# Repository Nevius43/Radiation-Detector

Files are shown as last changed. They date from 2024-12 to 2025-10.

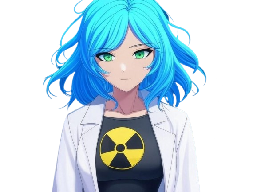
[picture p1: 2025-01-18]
User Interface/SquareLineFiles/cache/thumb_83886609image-removebg-preview.png

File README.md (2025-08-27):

# ESP32-S3 Radiation Detector

A small, open-source handheld **radiation detector/logger** based on the **ESP32-S3**.  
It reads a **Geiger–Müller (GM) tube** and can optionally handle a **scintillation probe (CsI(Tl) + SiPM)**.  
Data is shown on a **4" SPI TFT** and can be logged to **microSD**.

> ⚠️ **Safety:** This project uses **high voltage (≈400–600 V)** and is **not** a certified dosimeter. Build and use at your own risk.

---

## Features
- Live CPS/CPM and rough µSv/h estimate (tube-dependent factor).
- Optional scintillation input through a simple analog chain + discriminator.
- 4" SPI TFT with resistive touch; buzzer clicks/alarms.
- microSD CSV logging (timestamp, cps/cpm, battery, HV, etc.).
- Li-Po power, USB charging, 3.3 V buck; battery voltage monitor.
- Simple config via `src/config.h`. PlatformIO project.

---

## Hardware (summary)
- **MCU:** ESP32-S3-WROOM-1U-N16R8  
- **Display:** ST7796S (SPI) + XPT2046 touch (SPI)  
- **Storage:** microSD (SPI)  
- **GM subsystem:** HV boost (~500 V) + GM input (e.g., Philips 18504)  
- **Optional scintillation:** CsI(Tl) + SiPM (e.g., MicroFC-60035)  
- **Power:** MCP73831 charger, SY8089 buck, battery divider to ADC

Full schematics/PCB are in `/PCB`.

---

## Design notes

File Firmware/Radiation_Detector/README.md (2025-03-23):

# Radiation Detector

A digital radiation monitoring system built on the ESP32-S3 platform with real-time radiation measurement, visualization, data logging, and wireless connectivity.

Radiation Detector

## Overview

This radiation detector project combines an ESP32-S3 microcontroller with a Geiger counter to create a versatile digital radiation monitoring system. It features a touchscreen TFT display for data visualization, WiFi connectivity for remote monitoring, and OTA (Over-The-Air) update capabilities.

The system provides:

- Real-time measurement of radiation levels in µSv/h
- Historical data visualization with 1-hour and 24-hour charts
- Customizable alarm thresholds for radiation levels
- Web dashboard for remote monitoring
- OTA firmware updates
- mDNS support for easy access via "radiation.local"

## Hardware Requirements

- ESP32-S3 development board
- Geiger counter module (connected to GPIO 9)
- 3.5" TFT display (480x320)
- Buzzer (connected to GPIO 38)
- USB power supply

## Software Architecture

The project is built with PlatformIO and Arduino framework and consists of several key components:

1. **Radiation Measurement** - Uses ESP32's PCNT (Pulse Counter) peripheral to count pulses from the Geiger counter
2. **User Interface** - LVGL-based touchscreen interface with multiple screens
3. **Data Visualization** - Real-time and historical charts showing radiation levels
4. **Web Dashboard** - Remote monitoring capabilities
5. **OTA Updates** - Wireless firmware update functionality
6. **mDNS Support** - Local network hostname resolution (radiation.local)

## Installation

### Prerequisites

- [PlatformIO](https://platformio.org/) (with VS Code or CLI)
- The following libraries (installed automatically via PlatformIO):
  - LVGL (for UI)
  - TFT_eSPI (for display)
  - ArduinoJson
  - ElegantOTA
  - ESPmDNS

### Building and Flashing

1. Clone the repository:
   ```
   git clone https://github.com/username/Radiation-Detector.git
   ```

2. Open the project in PlatformIO:
   ```
   cd Radiation-Detector
   platformio open
   ```

3. Build and upload to your ESP32-S3:
   ```
   platformio run --target upload
   ```

## Usage

### Physical Interface

The device starts with a startup screen showing the bootup sequence. Once initialized:

1. **Main Screen** - Displays current radiation readings with four key metrics:
   - Current Radiation (µSv/h)
   - Average Radiation (µSv/h)
   - Maximum Radiation (µSv/h)
   - Cumulative Dose (mSv)

2. **Charts Screen** - Provides visual history of radiation levels:
   - 1-hour chart (20 segments of 3-minute averages)
   - 24-hour chart (24 segments of 1-hour averages)

3. **Settings Screen** - Configuration options:
   - WiFi connection setup
   - Alarm threshold settings
   - Display settings

### Web Interface

Once connected to WiFi, the device hosts a web dashboard accessible through:

- IP address (displayed on the screen)
- mDNS hostname: http://radiation.local

The web dashboard provides:
- Current radiation readings
- Historical charts
- OTA update functionality (with safety confirmation)

## Configuration

### WiFi Setup

1. On the Settings screen, enter your WiFi credentials
2. Toggle "Connect on Startup" to enable automatic connection
3. Press "Connect" to initiate connection

### Alarm Settings

1. Navigate to the Settings screen
2. Set threshold for current radiation level (µSv/h)
3. Set threshold for cumulative dose (mSv)
4. Enable/disable alarm function using the checkbox

## Technical Details

### Radiation Measurement

- The system uses an ESP32 PCNT peripheral to count pulses from the Geiger counter
- Pulses are sampled every 100ms and accumulated into 1-second intervals
- Conversion factor: 153.8 pulses/minute = 1 µSv/h (calibrated for specific Geiger tube)
- 60-second running average for current readings to reduce statistical noise

### Data Visualization

- 1-hour chart: 20 segments, each representing a 3-minute average
- 24-hour chart: 24 segments, each representing a 1-hour average
- Dynamic Y-axis scaling based on measured values

### Power Management

- Display dimming after 5 minutes of inactivity
- Touch anywhere to restore display brightness
- USB-powered design (no battery monitoring)

## OTA Updates

The device supports Over-The-Air updates via the web interface:

1. Access the web dashboard at http://radiation.local
2. Navigate to the update page
3. Review and acknowledge the warning
4. Select and upload the new firmware file

## Development

### Project Structure

- `src/Radiation-Detector.cpp` - Main application code
- `src/dashboard.*` - Web dashboard implementation
- `src/radiation_data.h` - Data exchange interface
- `src/ui.*` - UI components and layout

### Adding Features

To extend the project:

1. Modify UI elements in `ui.c` and `ui.h`
2. Update web dashboard in `dashboard.cpp`
3. Add new hardware interfaces in `Radiation-Detector.cpp`

## Troubleshooting

- **WiFi Connection Issues**: Check credentials, try manual connection
- **No Radiation Readings**: Verify Geiger counter connection to GPIO 9
- **Display Not Working**: Check TFT connections and initialization
- **OTA Update Failing**: Ensure stable WiFi connection, verify firmware file

## License

This project is licensed under the MIT License - see the LICENSE file for details.

## Acknowledgments

- LVGL for the UI framework
- TFT_eSPI library for display support
- ElegantOTA for update functionality
- ESPmDNS for local hostname support

## Safety Warning

This device is meant for educational and hobbyist purposes only. It should not be used as a primary radiation safety device in hazardous environments. Always use certified radiation detection equipment for critical safety applications.

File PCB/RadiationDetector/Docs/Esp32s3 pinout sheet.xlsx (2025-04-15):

1 | GND_1
2 | 3V3
3 | EN
4 | GPIO4/RTC_GPIO4/TOUCH4/ADC1_CH3
5 | GPIO5/RTC_GPIO5/TOUCH5/ADC1_CH4
6 | GPIO6/RTC_GPIO6/TOUCH6/ADC1_CH5
7 | GPIO7/RTC_GPIO7/TOUCH7/ADC1_CH6
8 | GPIO15/RTC_GPIO15/U0RTS/ADC2_CH4/XTAL_32K_P
9 | GPIO16/RTC_GPIO16/U0CTS/ADC2_CH5/XTAL_32K_N
10 | GPIO17/RTC_GPIO17/U1TXD/ADC2_CH6
11 | GPIO18/RTC_GPIO18/U1RXD/ADC2_CH7/CLK_OUT3
12 | GPIO8/RTC_GPIO8/TOUCH8/ADC1_CH7/SUBSPICS1
13 | USB_D/RTC_GPIO19/GPIO19/U1RTS/ADC2_CH8/CLK_OUT2
14 | USB_D+/RTC_GPIO20/GPIO20/U1CTS/ADC2_CH9/CLK_OUT1
15 | GPIO3/RTC_GPIO3/TOUCH3/ADC1_CH2
16 | GPIO46
17 | GPIO9/RTC_GPIO9/TOUCH9/ADC1_CH8/FSPIHD/SUBSPIHD
18 | GPIO10/RTC_GPIO10/TOUCH10/ADC1_CH9/FSPICS0/FSPIIO4/SUBSPICS0
19 | GPIO11/RTC_GPIO11/TOUCH11/ADC2_CH0/FSPID/FSPIIO5/SUBSPID
20 | GPIO12/RTC_GPIO12/TOUCH12/ADC2_CH1/FSPICLK/FSPIIO6/SUBSPICLK
21 | GPIO13/RTC_GPIO13/TOUCH13/ADC2_CH2/FSPIQ/FSPIIO7/SUBSPIQ
22 | GPIO14/RTC_GPIO14/TOUCH14/ADC2_CH3/FSPIWP/FSPIDQS/SUBSPIWP
23 | GPIO21/RTC_GPIO21
24 | GPIO47/SPICLK_P_DIFF/SUBSPICLK_P_DIFF
25 | GPIO48/SPICLK_N_DIFF/SUBSPICLK_N_DIFF
26 | GPIO45
27 | GPIO0/RTC_GPIO0
28 | GPIO35/SPIIO6/FSPID/SUBSPID
29 | GPIO36/SPIIO7/FSPICLK/SUBSPICLK
30 | GPIO37/SPIDQS/FSPIQ/SUBSPIQ
31 | GPIO38/FSPIWP/SUBSPIWP
32 | MTCK/GPIO39/CLK_OUT3/SUBSPICS1
33 | MTDO/GPIO40/CLK_OUT2
34 | MTDI/GPIO41/CLK_OUT1
35 | MTMS/GPIO42
36 | U0RXD/GPIO44/CLK_OUT2
37 | U0TXD/GPIO43/CLK_OUT1
38 | GPIO2/RTC_GPIO2/TOUCH2/ADC1_CH1
39 | GPIO1/RTC_GPIO1/TOUCH1/ADC1_CH0
40 | GND_2
41 | GND_3
42 | GND_4
43 | GND_5
44 | GND_6
45 | GND_7
46 | GND_8
47 | GND_9
48 | GND_10
49 | GND_11

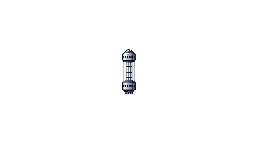
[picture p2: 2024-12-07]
User Interface/SquareLineFiles/cache/thumb_86797815Diseño sin título.png

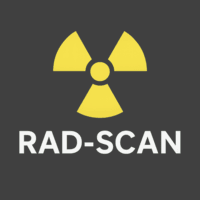
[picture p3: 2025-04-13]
User Interface/SquareLineFiles/assets/RadScan200x200.png

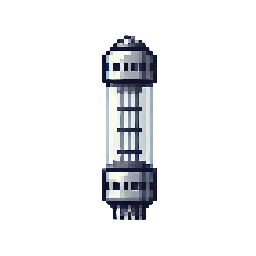
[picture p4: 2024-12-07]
User Interface/SquareLineFiles/cache/thumb_1336107941GMtube.png

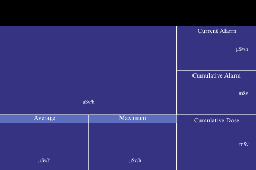
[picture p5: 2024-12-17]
User Interface/SquareLineFiles/cache/thumb_735237340El texto del párrafo.png

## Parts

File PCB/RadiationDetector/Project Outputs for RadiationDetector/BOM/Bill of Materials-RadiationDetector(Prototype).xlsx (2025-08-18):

Comment | Description | Designator | Footprint | LibRef | Quantity | LCSC Part Number | Manufacturer Part Number | Supplier Part Number | Supplier | Manufacturer
1uF, 16V | CAP CER 1UF 16V X5R 0402 | C3, C25 | CAP 0402_1005 | CL05A105KO5NNNC | 2 | C29266 | CL05A105KO5NNNC | 1276-1067-1-ND | Digikey | Samsung Electro-Mechanics
10uF, 10V | CAP CER 10UF 10V X5R 0402 | C4, C15 | CAP 0402_1005 | CL05A106MP8NUB8 | 2 | C307415 | CL05A106MP8NUB8 | 1276-6830-1-ND | Digikey | Samsung Electro-Mechanics
0.1uF, 50V | CAP CER 0.1UF 50V X7R 0402 | C5, C6, C8, C9, C10, C11, C14, C16, C22, C24 | CAP 0402_1005 | CL05B104KB5NNNC | 10 | C960916 | CL05B104KB5NNNC | CL05B104KB5NNNC | Avnet | Samsung
4u7 6.3V | CAP CER 4.7UF 6.3V X5R 0402 | C7, C17, C18 | CAP 0402_1005 | CL05A475KQ5NRNC | 3 | C2932473 | CL05A475KQ5NRNC | 1276-1481-1-ND | Digikey | Samsung
470p 50V | CAP CER 470PF 50V X7R 0402 | C12 | CAP 0402_1005 | CL05B471KB5VPNC | 1 | C472438 | CL05B471KB5VPNC | 1276-6586-1-ND | Digikey | Samsung
220p 50V | CAP CER 220PF 50V X7R 0402 | C13, C29 | CAP 0402_1005 | CL05B221KB5NNNC | 2 | C296710 | CL05B221KB5NNNC | 1276-1531-1-ND | Digikey | Samsung
2 Pin JST | Board Connector, 2 Contact(s), 1 Row(s), Male, Straight, 0.079 inch Pitch, Solder Terminal, Locking, Natural Insulator | C19 | JST_B2B-PH-K-S | B2B-PH-K-S(LF)(SN) | 1 | C131337 | B2B-PH-K-S(LF)(SN) | 9491856 | Farnell | JST
22u 6.3V | CAP CER 22UF 6.3V X5R 0603 | C20, C21 | CAPC1608X90 | CL10A226MQ8NRNC | 2 | C59461 | CL10A226MQ8NRNC | 1276-1193-1-ND | Digikey | Samsung
220u 6.3V | CAP CER 220UF 6.3V X5R 1210 | C23 | ANTC3225X280N | CL32A227MQVNNNE | 1 | C400951 | CL32A227MQVNNNE | 1276-3375-6-ND | Digikey | Samsung
10nF 1KV | CAP CER 10000PF 1KV X7R 1206 | C26, C27 | CAP 1206_3216 - 1.2MM | CC1206KKX7RCBB103 | 2 | C107192 | CC1206KKX7RCBB103 | 311-1500-1-ND | Digikey | Yageo
330pF 100V | CAP CER 330PF 100V C0G/NPO 0805 | C28 | CAPC2012X94N | CC0805JRNPO0BN331 | 1 | C113820 | CC0805JRNPO0BN331 | 311-3287-1-ND | Digikey | Yageo
10 pF 1KV | CAP CER 10PF 1KV C0G/NPO 1206 | C31 | CAP 1206_3216 - 1.2MM | CC1206JKNPOCBN100 | 1 | C107172 | CC1206JKNPOCBN100 | 311-1912-6-ND | Digikey | Yageo
1N5819HW-7-F | DIODE SCHOTTKY 40V 1A SOD123 | D1, D5, D11 | FP-SOD123-MFG | 1N5819HW-7-F | 3 | C82544 | 1N5819HW-7-F | 1N5819HW-FDICT-ND | Digikey | Diodes
ESD5B5.0ST1G | TVS DIODE 5VWM SOD523 | D2, D3, D4, D6, D7, D8 | ONSC-SOD-523-2-502-01_C_V | ESD5B5.0ST1G | 6 | C93623 | ESD5B5.0ST1G | ESD5B5.0ST1GOSCT-ND | Digikey | ON Semiconductor
PMEG4010BEA,115 | DIODE SCHOTTKY 40V 1A SOD323 | D9, D10 | SOD2512X110N | PMEG4010BEA,115 | 2 | C36975 | PMEG4010BEA,115 | 1727-5211-1-ND | Digikey | Nexperia
RED LED | LED RED CLEAR SMD | D12 | FP-LTST-C171KGKT-MFG | LTST-C171KGKT | 1 | C284871 | LTST-C171KGKT | 160-1426-6-ND | Digikey | Vishay Lite-On
RS2MBF | 2A 1000V 1.3V SMB-FL Diodes - General Purpose ROHS | D13 | RS2MBF | RS2MBF | 1 | C5271853
3SMAJ5951B-TP | DIODE ZENER 120V 3W DO214AC | D14, D15, D16, D17, D18 | DIOM4325X244N | 3SMAJ5951B-TP | 5 | C511105 | 3SMAJ5951B-TP | 3SMAJ5951B-TPMSCT-ND | Digikey | MCC
BAS21 | DIODE STANDARD 250V 200MA SOT233 | D19, D20 | SOT-23 | BAS21 | 2 | C8661 | BAS21 | 9843728 | Farnell | onsemi
ESP32-S3-WROOM-1U-N16R8 | SMD Module, ESP32-S3R8 With 8 mb | ESP32-S3-WROOM-1U-N16R8 | ESP32S3WROOM1N8R2 | ESP32-S3-WROOM-1-N16R8 | 1 | C2913202 | ESP32-S3-WROOM-1U-N16R8 | 1965-ESP32-S3-WROOM-1U-N16R8CT-ND | Digikey | Espressif Systems
2171790001 | CONN RCP USB2.0 TYP C 24P SMD RA | G1, G2 | FP-2171790001-MFG | 217179-0001 | 2 | C3197684 | 217179-0001 | 900-2171790001CT-ND | Digikey | Molex
2.2 uH | 1.35A 2.2uH ±20% 1.35A SMD,3x3mm Power Inductors ROHS | L1 | IND_VLS3015ET-220M-CA | VLS3015ET-2R2M | 1 | C76864 | VLS3015ET-2R2M | 445-6675-1-ND | Digikey | TDK
1mH 1.850R | FIXED IND 1MH 520MA 1.85 OHM SMD | L2 | 48102SC | 48102SC | 1 | C5223670 | 48102SC | 811-3598-1-ND | Digikey | Murata
PS1720P02 | Data Line Filter, 1 Function(s) | LS1 | FP-PS1720P02-MFG | PS1720P02 | 1 | C96061
SS8050-G | Transistores - Bipolar (BJT) - Simple NPN 25 V 1.5 A 100MHz 300 mW Montaje en superficie SOT-23-3 | Q1, Q2 | FP-SS8050-G-IPC_B | SS8050-G | 2 | C164886 | SS8050-G | 641-1790-1-ND | Digikey | Comchip
2N7002 | MOSFET SOT23 N 60V 5OHM 150C | Q3 | SOT95P240X111-3N | 2N7002 | 1 | C124475 | 2N7002 | 2N7002NCT-ND | Digikey | ON Semiconductor / Fairchild
WPM2015-3/TR | 20V 2.4A 110mΩ@4.5V,2.7A 1.1W 1V@250uA 1 P-Channel SOT-23-3 MOSFETs ROHS | Q4 | SOT-23 | WPM2015-3/TR | 1 | C6562215
HX2300A | 20V 2.5A 46mΩ@4.5V,2.5A 650mV 1 N-channel SOT-23 MOSFETs ROHS | Q5 | SOT-23 | HX2300A | 1 | C296302
STD3NK80ZT4 | MOSFET N-CH 800V 2.5A DPAK | Q6 | DPAK_STM | STD3NK80ZT4 | 1 | C411398 | STD3NK80ZT4 | 497-7968-1-ND | Digikey | STMicroelectronics
0R | RES 0 OHM JUMPER 1/16W 0402 | R1, R5 | RESC1005X37N | RC0402JR-070RL | 2 | C60485 | RC0402JR-070RL | 311-0.0JRCT-ND | Digikey | Yageo
10K | RES SMD 10K OHM 1% 1/16W 0402 | R2, R3, R4, R11, R32 | RESC1005X37N | AC0402FR-0710KL | 5 | C144807 | AC0402FR-0710KL | YAG3436CT-ND | Digikey | Yageo
27R | RES SMD 27 OHM 1% 1/16W 0402 | R6, R7 | RESC1005X37N | AC0402FR-0727RL | 2 | C226392 | AC0402FR-0727RL | YAG5278CT-ND | Digikey | Yageo
4K7 | RES SMD 4.7K OHM 1% 1/16W 0402 | R8 | RESC1005X37N | AC0402FR-074K7L | 1 | C174364 | AC0402FR-074K7L | YAG3497CT-ND | Digikey | Yageo
5k1 | RES SMD 5.1K OHM 1% 1/16W 0402 | R9, R10, R12, R13 | RESC1005X37N | AC0402FR-075K1L | 4 | C144745 | AC0402FR-075K1L | YAG3503CT-ND | Digikey | Yageo
2K | TRIMMER 2K OHM 0.25W J LEAD TOP | R14 | TRIM_3314J-1-202E | 3314J-1-202E | 1 | C94513 | 3314J-1-202E | 3314J-202ECT-ND | Digikey | Bourns
1K | RES SMD 1K OHM 5% 1/16W 0402 | R15, R19, R21 | RESC1005X37N | AC0402JR-071KL | 3 | C138287 | AC0402JR-071KL | YAG3525CT-ND | Digikey | Yageo
150R | RES SMD 150 OHM 1% 1/16W 0402 | R16, R22 | RESC1005X37N | AC0402FR-07150RL | 2 | C226790 | AC0402FR-07150RL | YAG3443DKR-ND | Digikey | Yageo
47K | RES SMD 47K OHM 1% 1/16W 0402 | R17 | RESC1005X37N | AC0402FR-0747KL | 1 | C144757 | AC0402FR-0747KL | YAG3490CT-ND | Digikey | Yageo
50R | RES SMD 50 OHM 0.1% 1/16W 0402 | R18 | RESC1005X37N | RT0402BRE0750RL | 1 | C853312 | RT0402BRE0750RL | 13-RT0402BRE0750RLCT-ND | Digikey | Yageo
10K | TRIMMER 10K OHM 0.25W GW TOP ADJ | R20 | TS53YL_VIS | TS53YL103MR10 | 1 | C5189226 | TS53YL103MR10 | TS53YL-10KCT-ND | Digikey | Vishay
2KR | RES 2K OHM 1% 1/16W 0402 | R23 | RESC1005X37N | AC0402FR-132KL | 1 | C144770 | AC0402FR-132KL | 13-AC0402FR-132KLDKR-ND | Digikey | Yageo
220K | RES 220K OHM 5% 1/16W 0402 | R24 | RESC1005X37N | RC0402JR-07220KL | 1 | C137900 | RC0402JR-07220KL | 311-220KJRCT-ND | Digikey | Yageo
49.9K | RES 49.9K OHM 1% 1/16W 0402 | R25 | RESC1005X37N | RC0402FR-0749K9L | 1 | C137969 | RC0402FR-0749K9L | 311-49.9KLRCT-ND | Digikey | Yageo
470K | RES 470K OHM 5% 1/16W 0402 | R26 | RESC1005X37N | RC0402JR-07470KL | 1 | C137865 | RC0402JR-07470KL | 311-470KJRDKR-ND | Digikey | Yageo
150K | RES 150K OHM 5% 1/16W 0402 | R27 | RESC1005X37N | RC0402JR-07150KL | 1 | C93947 | RC0402JR-07150KL | 311-150KJRCT-ND | Digikey | Yageo
560R | RES SMD 560 OHM 1% 1/16W 0402 | R28 | RESC1005X37N | AC0402FR-07560RL | 1 | C144747 | AC0402FR-07560RL | 13-AC0402FR-07560RLCT-ND | Digikey | Yageo
1M | RES SMD 1M OHM 1% 1/16W 0402 | R29 | RESC1005X37N | AC0402FR-071ML | 1 | C144787 | AC0402FR-071ML | YAG3450CT-ND | Digikey | Yageo
10M | RES SMD 10M OHM 1% 1/16W 0402 | R30 | RESC1005X37N | AC0402FR-0710ML | 1 | C144806 | AC0402FR-0710ML | YAG3437CT-ND | Digikey | Yageo
4.99M | RES 4.99M OHM 1% 1/4W 1206 | R31, R33, R34 | RESC3116X65N | RC1206FR-074M99L | 3 | C488845 | RC1206FR-074M99L | 311-4.99MFRDKR-ND | Digikey | Yageo
82K | RES SMD 82K OHM 1% 1/16W 0402 | R35 | RESC1005X37N | AC0402FR-0782KL | 1 | C144735 | AC0402FR-0782KL | YAG5311CT-ND | Digikey | Yageo
200K | RES SMD 200K OHM 1% 1/16W 0402 | R36 | RESC1005X37N | AC0402FR-07200KL | 1 | C144785 | AC0402FR-07200KL | YAG3452CT-ND | Digikey | Yageo
2M | RES SMD 2M OHM 1% 1/16W 0402 | R37 | RESC1005X37N | AC0402FR-072ML | 1 | C138293 | AC0402FR-072ML | 13-AC0402FR-072MLDKR-ND | Digikey | Yageo
3M | RES SMD 3M OHM 5% 1/16W 0402 | R38 | RESC1005X37N | AC0402JR-073ML | 1 | C227371 | AC0402JR-073ML | 13-AC0402JR-073MLCT-ND | Digikey | Yageo
100K | RES SMD 100K OHM 1% 1/16W 0402 | R39 | RESC1005X37N | AC0402FR-07100KL | 1 | C144809 | AC0402FR-07100KL | YAG3434CT-ND | Digikey | Yageo
PTS645SH50SMTR92 LFS | SWITCH TACTILE SPST-NO 0.05A 12V | SW1, SW2 | FP-PTS645SH50SMTR92LFS-MFG | PTS645SH50SMTR92LFS | 2 | C221869 | PTS645SH50SMTR92LFS | CKN9085CT-ND | Digikey | ITT C&K
MK-12C02-G015 | Surface Mount, Right Angle 1A SPDT 6V Black 10,000 Cycles SMD Slide Switches ROHS | SW3 | Switch | MK-12C02-G015 | 1 | C2911519
FT231XQ-R | IC USB SERIAL FULL UART 20QFN | U1 | FP-QFN-20-MFG | FT231XQ-R | 1 | C132159 | FT231XQ-R | 768-1128-1-ND | Digikey | FTDI
OPA2354AIDGKR | IC OPAMP VFB 2 CIRCUIT 8VSSOP | U2, U3, U4, U5 | DGK0008A_M | OPA2354AIDGKR | 4 | C95502 | OPA2354AIDGKR | 296-12642-2-ND | Digikey | Texas Instruments
MCP73831T-2ACI/OT | Power Supply Support Circuit, Adjustable, 1 Channel, PDSO5 | U6 | FP-C04-091-OT-IPC_B | MCP73831T-2ACI/OT | 1 | C424093 | MCP73831T-2ACI/OT | 1332158 | Farnell | Microchip
SY8089AAAC | Buck Adjustable 2A 2.7V~5.5V SOT-23-5 DC-DC Converters ROHS | U7 | SOT95P285X140-5N | SY8089AAAC | 1 | C78988
TLV3691IDCKR | IC COMPARATOR 1 GEN PUR SC70-5 | U30 | FP-DCK0005A-IPC_B | TLV3691IDCKR | 1 | C180352 | TLV3691IDCKR | 296-37910-1-ND | Digikey | Texas Instruments
VLS3015CX-2R2M-1
TLV3542IDGKR

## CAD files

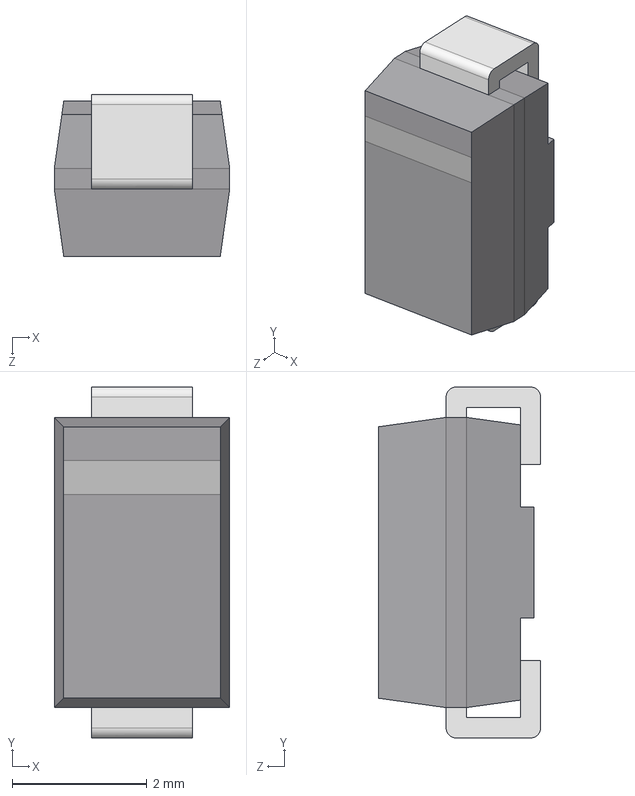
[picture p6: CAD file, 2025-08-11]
PCB/RadiationDetector/3D/User Library-DO-214AC SMA.STEP
2.60 x 5.20 x 2.40 mm

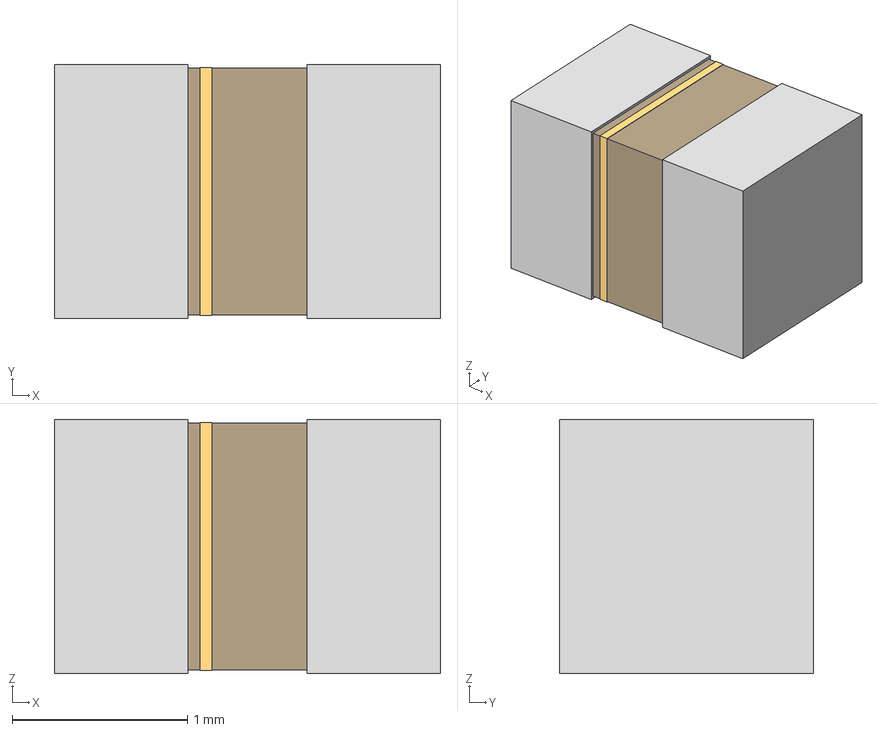
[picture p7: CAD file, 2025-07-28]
PCB/RadiationDetector/tmp/CAP_CC0805_YAG.step
2.20 x 1.45 x 1.45 mm

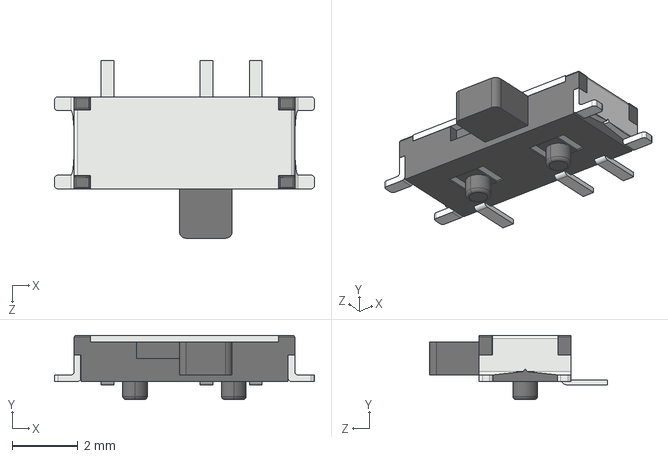
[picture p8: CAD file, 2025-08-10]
PCB/RadiationDetector/3D/mkswitch.STEP
7.90 x 1.95 x 5.39 mm

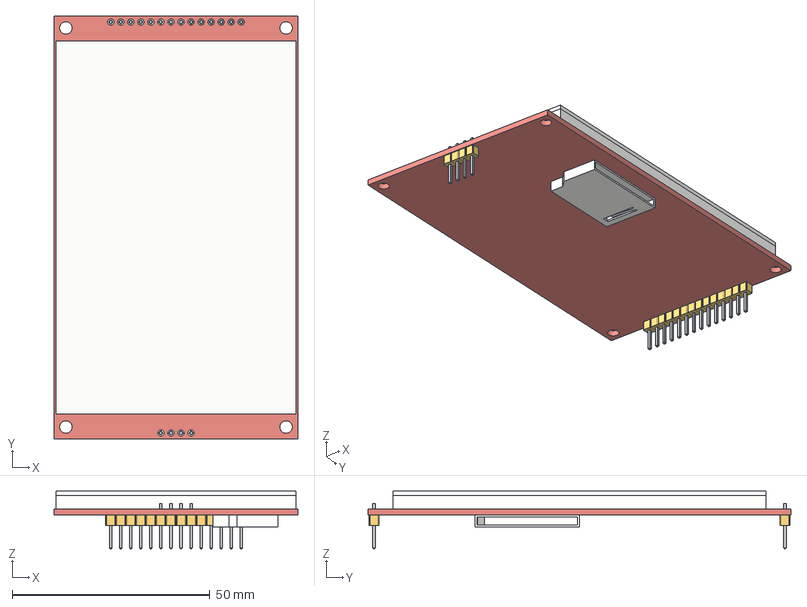
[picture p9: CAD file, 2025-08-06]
PCB/RadiationDetector/3D/ST7796SDisplay.step
61.8 x 107.0 x 14.7 mm
Glass
TFT Screen 480x320
Annular Rings
SD Card
Pins

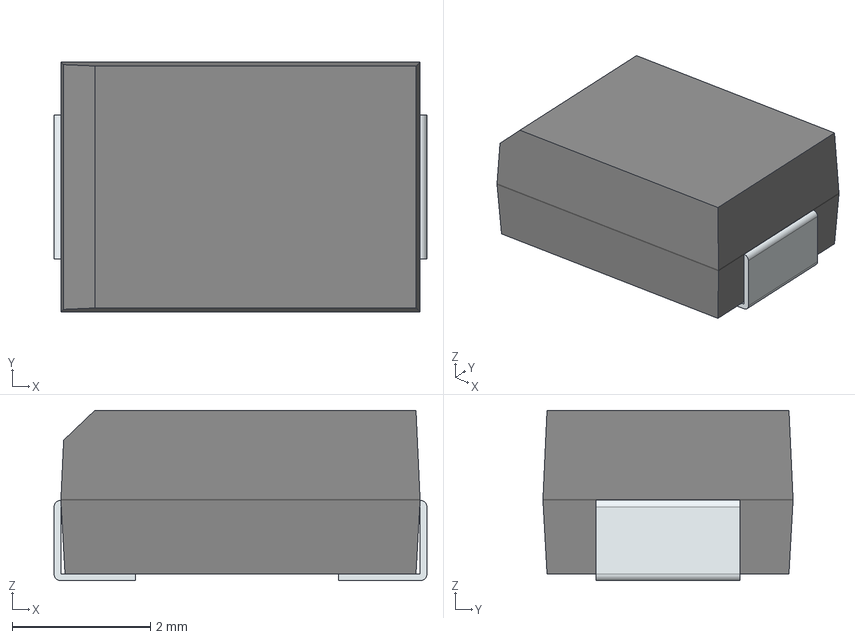
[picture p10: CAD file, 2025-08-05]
PCB/RadiationDetector/3D/MBRS240LT3G.stp
5.41 x 3.62 x 2.47 mm
FilletPin1
FilletPin2

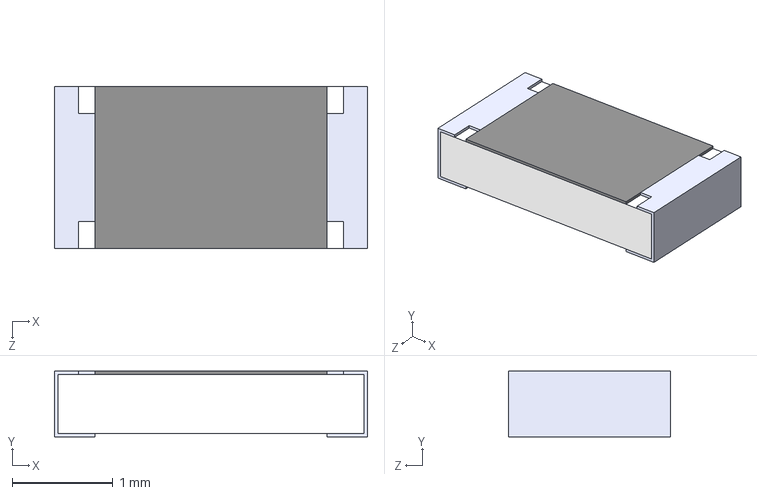
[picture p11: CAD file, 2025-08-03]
PCB/RadiationDetector/3D/RC1206FR-074M99L.STEP
3.10 x 0.65 x 1.60 mm

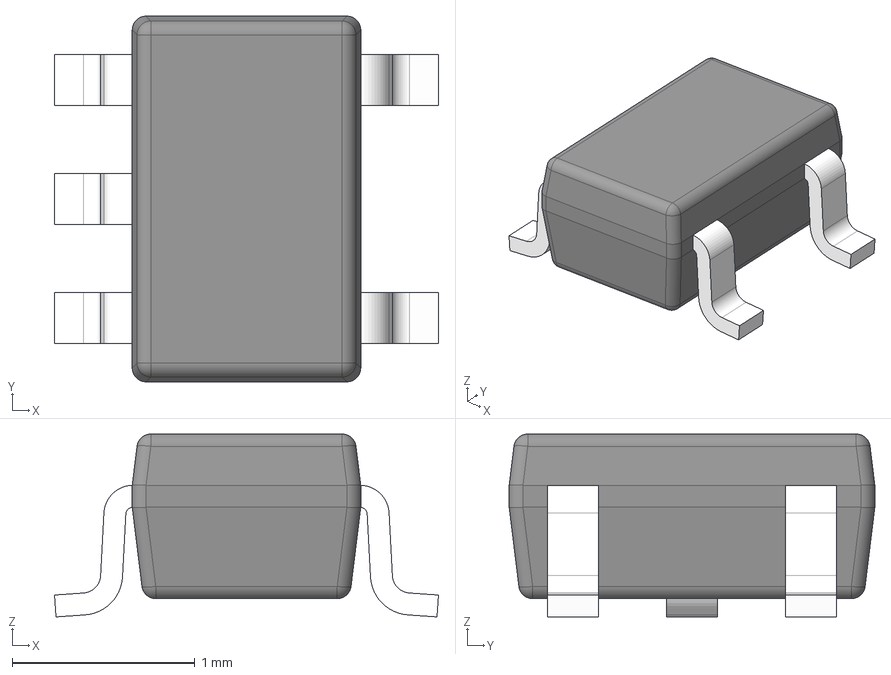
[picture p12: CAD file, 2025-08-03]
PCB/RadiationDetector/3D/TLV3691IDCKR.stp
2.10 x 2.00 x 1.00 mm
BODY-SOT
LEAD-SOT x 5
PIN1-ID

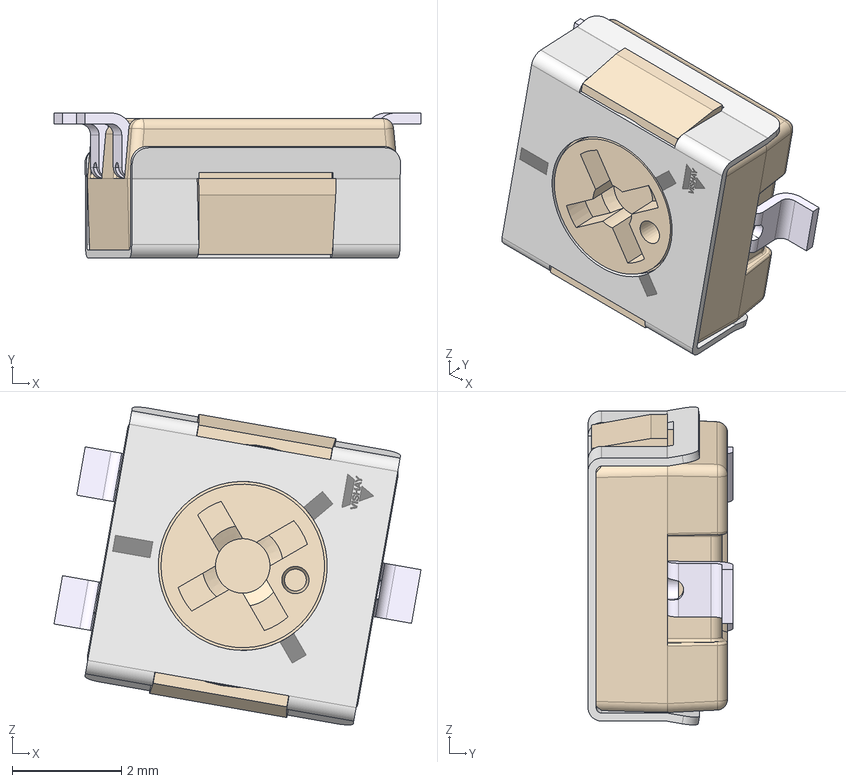
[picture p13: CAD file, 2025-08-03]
PCB/RadiationDetector/3D/TS53YLxxx.stp
6.73 x 2.66 x 5.83 mm
substrat seul
3935201-L

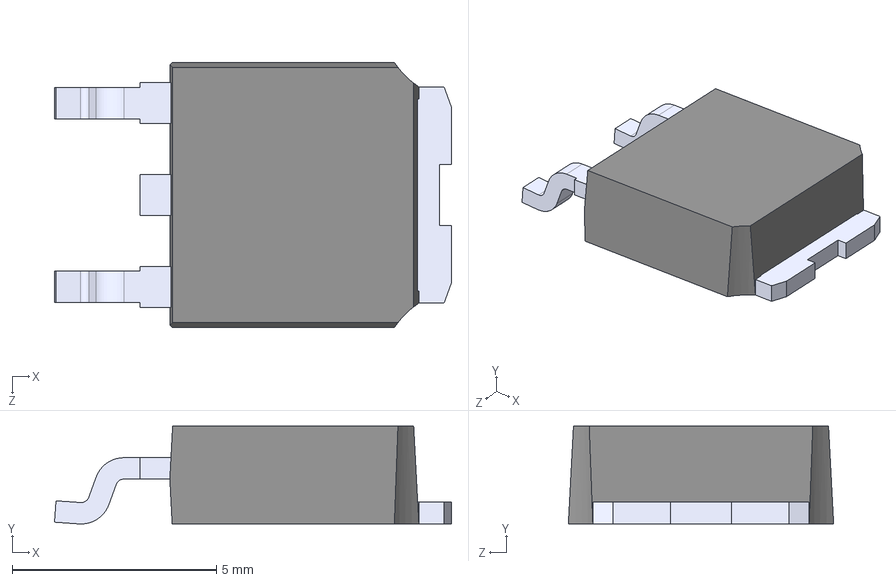
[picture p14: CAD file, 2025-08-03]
PCB/RadiationDetector/3D/STD3NK80ZT4.step
9.72 x 2.40 x 6.50 mm

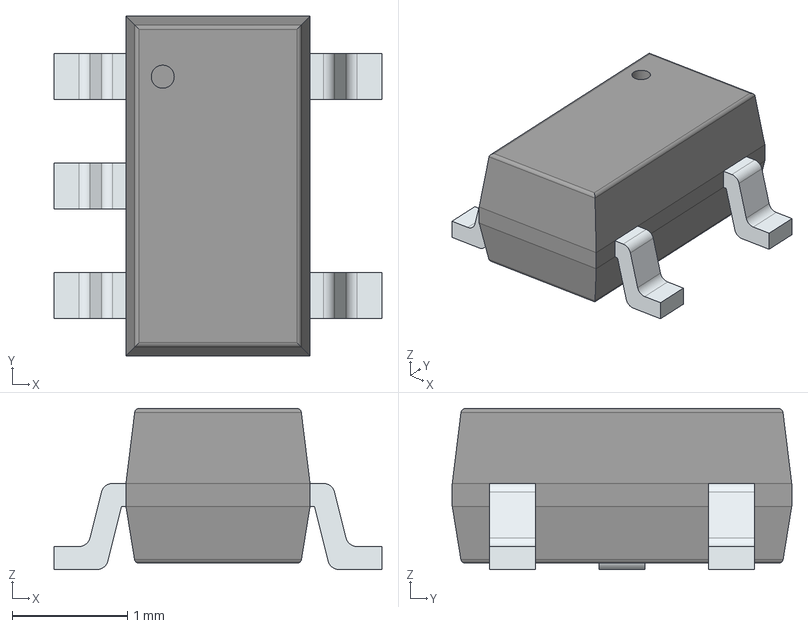
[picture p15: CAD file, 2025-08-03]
PCB/RadiationDetector/3D/SMD_IC_SY8089AAAC.stp
2.85 x 2.95 x 1.40 mm
PinsArrayL
PinsArrayR

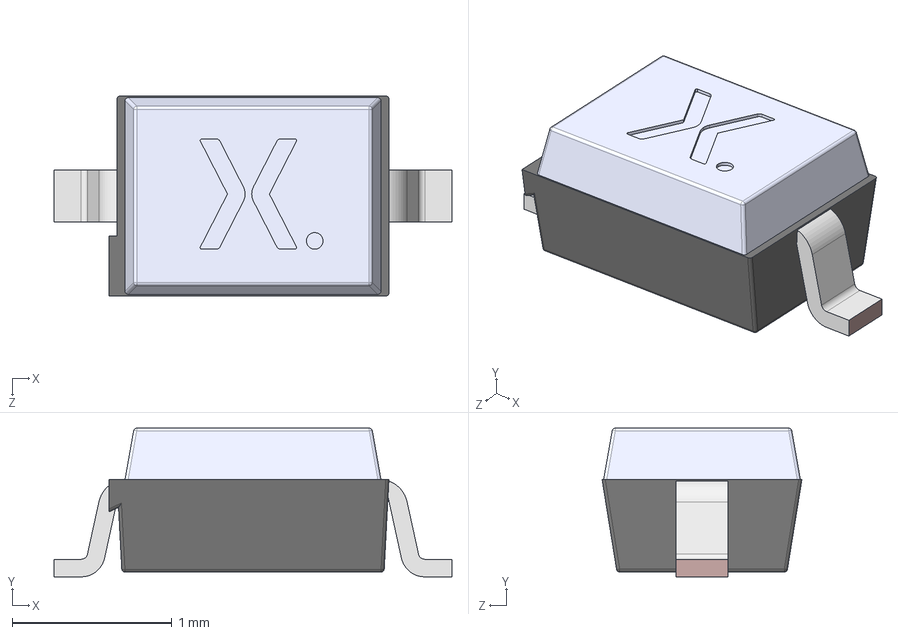
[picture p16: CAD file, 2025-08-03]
PCB/RadiationDetector/3D/PMEG4010BEA,115.stp
2.49 x 0.93 x 1.25 mm
SOD323 Lower body
SOD323 Lead x 2
SOD323 Upper body

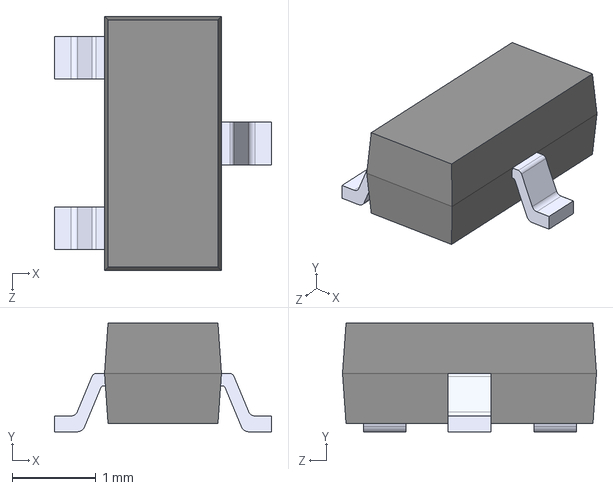
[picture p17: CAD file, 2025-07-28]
PCB/RadiationDetector/3D/2N7002.STEP
2.60 x 1.30 x 3.04 mm

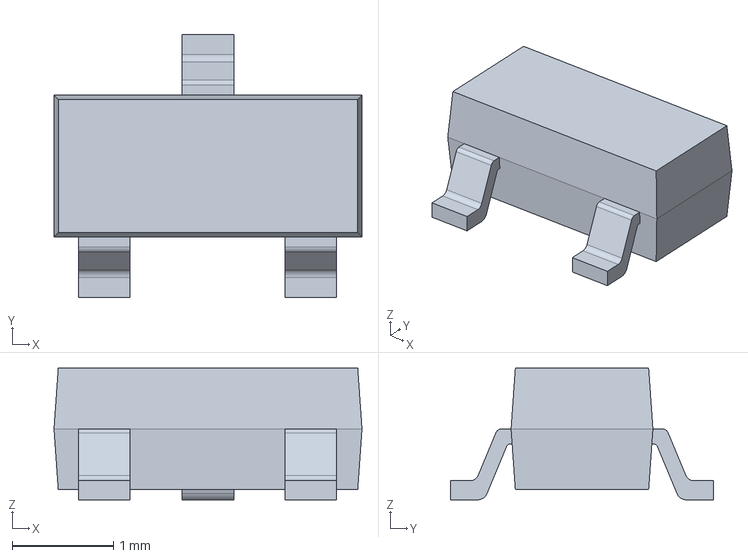
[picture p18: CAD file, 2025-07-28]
PCB/RadiationDetector/3D/BAS21.STEP
3.04 x 2.60 x 1.30 mm

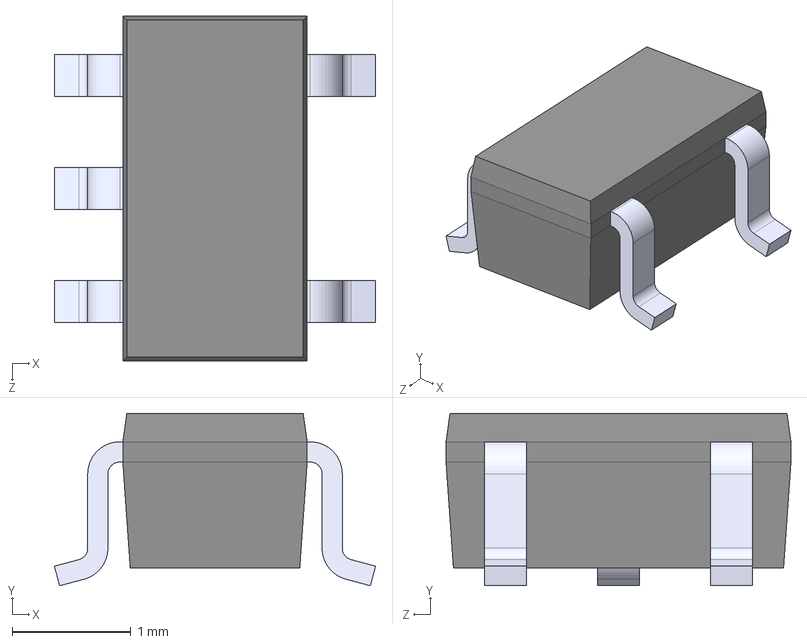
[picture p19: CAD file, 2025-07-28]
PCB/RadiationDetector/3D/OT.STEP
2.70 x 1.45 x 2.90 mm

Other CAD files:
PCB/RadiationDetector/3D/3314J-1-202E.STEP
PCB/RadiationDetector/3D/PTS645SL43SMTR92-LFS.STEP
PCB/RadiationDetector/3D/48102SC.stp

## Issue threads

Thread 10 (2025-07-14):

Review and sanity‑check full schematic

Nevius43, 2025-07-14:
Verify all net connections against functional spec (power rails, signal paths).

Cross‑check component values, reference designators, and power‑up sequences.

Annotate any errors or missing connections for fixing.

Closed 2025-07-27.

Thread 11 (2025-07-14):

Incorporate schematic revision notes

Nevius43, 2025-07-14:
Apply corrections from the review (net fixes, component swaps).

Update any outdated symbols or footprints.

Re‑export a clean PDF of the revised schematic.

Closed 2025-07-27.

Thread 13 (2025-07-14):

Define PCB mechanical outline and layer stackup

Nevius43, 2025-07-14:
Import enclosure dimensions or sketch board outline.

Choose layer count, copper thickness, and material.

Document stackup in your board file.

Nevius43, 2025-08-14:
## Why we chose a 4-layer stackup

* **Clean return paths & lower EMI.** The design mixes a noisy HV boost (\~hundreds of volts) and digital logic with a very sensitive analog front-end (SiPM/GM pulse conditioning). A solid **L2 ground plane** gives short, predictable returns and shields the top layer; a **dedicated L3 plane** lets us distribute power with low impedance and place keep-outs under HV nets to reduce capacitive coupling and surface leakage.
* **Noise isolation.** Separating signal (L1/L4) from planes (L2/L3) helps keep the HV converter and fast digital edges from polluting the analog reference used by the pulse/spectrometry chain.
* **Routing density / DFM.** The board has a display, connectors, and tight analog around the detector. Two layers would force many jumpers and longer loops; 4 layers keeps the layout compact and reduces rework risk.
* **Future-proofing.** The extra plane and routing headroom make BOM/feature changes (e.g., different tubes/sensors) less risky without respinning the stack.

## Chosen stackup (documented in the PCB file)

* **Total thickness:** \~1.6 mm FR-4.
* **Copper:**

  * L1 (Top Signal): **1 oz (\~35 µm)**
  * L2 (GND plane): **0.5 oz (\~17 µm)**
  * L3 (Power/Shield plane): **0.5 oz (\~17 µm)**
  * L4 (Bottom Signal): **1 oz (\~35 µm)**
* **Dielectrics/materials:**

  * Prepregs: \~3.9 mil each, **Dk ≈ 4.1, Df ≈ 0.02**
  * Core: \~50 mil FR-4, **Dk ≈ 4.8**
* **Layer purposes:**

  * **L1:** Components, sensitive analog, short HV runs (with plane keep-out beneath).
  * **L2:** **Power plane** (split where needed), stitching caps to L3 for low ESL.
  * **L3:**  **Unbroken GND** (primary return for L1/L4; via-stitched shields around HV and clocks).
  * **L4:** Secondary routing, slow/control signals, I/O.

> Note: Inner copper is set lighter (0.5 oz) to help manufacturability and maintain dielectric thickness for better plane coupling; outer copper is 1 oz for current capacity and robustness.

## Enclosure & board outline

* **Enclosure dimensions imported** (STEP) and the **board shape sketched** to match the standoffs and I/O cutouts.
* **Mounting holes and keep-outs** added on Mechanical layers; height limits defined for the display module and the HV area.
* A keep-out/plane-relief is placed under nets >250 V to increase creepage, and we avoid pouring copper beneath the GM anode/HV nodes.

## Where this is documented

* The **Layer Stack Manager** in the PCB file now contains the full stackup (materials, thicknesses, Dk/Df, copper weights) and notes on L2/L3 plane intent.
* Board outline, mech holes, and height restrictions are saved in the PCB doc with clear layer naming (Mech-1: outline, Mech-2: standoffs, Mech-3: height limit).

If anything in the stack (e.g., inner copper weight) needs to be tuned to a specific fab’s defaults, I can adjust the values and re-export the stackup table.

Closed 2025-08-14.

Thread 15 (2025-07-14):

Place major modules on PCB

Nevius43, 2025-07-14:
Position high‑voltage Geiger tube circuitry, microcontroller, battery/charger.

Respect keep‑out zones and thermal considerations.

Annotate placement rationale for later review.

Closed 2025-08-11.

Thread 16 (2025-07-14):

Route power and high‑current nets

Nevius43, 2025-07-14:
Route battery, regulator, and HV traces with appropriate widths.

Add thermal reliefs and polygons for ground and power planes.

Ensure clearance rules for high‑voltage nets.

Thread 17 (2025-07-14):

Route signal and low‑voltage nets

Nevius43, 2025-07-14:
Complete routing for microcontroller I/O, display, and sensor lines.

Optimize trace lengths where timing matters.

Check impedance or filtering needs if applicable.

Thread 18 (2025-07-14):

Perform DRC/ERC and peer review

Nevius43, 2025-07-14:
Run design‐rule and electrical‐rule checks.

Fix any violations.

Share board file for a teammate’s review and incorporate feedback.

Closed 2025-08-17.

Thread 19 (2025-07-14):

Generate fabrication and assembly outputs

Nevius43, 2025-07-14:
Export Gerbers, drill files, assembly drawings, and BOM.

Package all outputs into a ZIP ready for manufacturer.

Update README with fabrication instructions.

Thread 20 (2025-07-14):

Define paper scope and outline

Nevius43, 2025-07-14:
Draft a high‑level outline: Introduction, Methods, Results, Discussion, Conclusion.

Specify key messages and target journal or conference format.

Allocate sections to your outline headings.

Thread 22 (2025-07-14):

Write Introduction and background

Nevius43, 2025-07-14:
Introduce radiation detection needs and battery‑powered constraints.

Summarize existing approaches and gaps.

State your contributions and paper organization.

Closed 2025-08-21.

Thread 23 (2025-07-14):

Describe hardware design and battery integration (Methods)

Nevius43, 2025-07-14:
Detail component selection, schematic revisions, and PCB design steps.

Explain battery chemistry choice, charger IC, and protection scheme.

Include key figures or schematics.

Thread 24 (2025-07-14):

Detail firmware implementation and power profiling

Nevius43, 2025-07-14:
Explain ADC‑based battery monitoring, low‑battery cutoff, and power‑saving modes.

Present measurement methodology for active vs. sleep currents.

Include code snippets or flowchart.

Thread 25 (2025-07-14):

Compile results: performance and endurance tests

Nevius43, 2025-07-14:
Tabulate runtime, voltage sag, temperature, and counting accuracy.

Generate any graphs (e.g., voltage vs. time).

Export figures and captions.

Closed 2025-08-31.

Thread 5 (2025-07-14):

Research and select suitable battery chemistry

Nevius43, 2025-07-14:
Compare Li‑ion, Li‑Po, NiMH, and alkaline options.

Consider size, capacity (mAh), discharge rates, safety, and cost.

Choose a candidate cell or pack.

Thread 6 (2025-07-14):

Choose and document a charging / protection IC

Nevius43, 2025-07-14:
Identify a charger/protection IC (e.g., MCP73831 for Li‑Po or TP4056).

Check features: charge current limit, undervoltage protection, thermal regulation.

Add schematics snippet and datasheet links.

Closed 2025-07-26.

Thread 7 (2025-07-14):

Design the battery power schematic

Nevius43, 2025-07-14:
Draft the battery + charger + protection + load schematic in your EDA tool.

Include decoupling caps, sense resistors, connector footprints.

Export for review.

Nevius43, 2025-07-26:
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

Closed 2025-07-26.

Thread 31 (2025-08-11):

Review microcontroller pin assignments and update spreadsheet

Nevius43, 2025-08-11:
Some discrepancies between the schematic and the pin spreadsheet were detected, fix them and set pins to optimize layout

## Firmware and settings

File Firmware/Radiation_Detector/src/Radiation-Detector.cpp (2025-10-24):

/**
 * @file main.cpp
 * @brief Radiation Monitor with TFT UI, WiFi OTA, and hardware pulse counting on ESP32S3.
 *
 * This file reads pulses from a Geiger counter via the ESP32 PCNT peripheral, displays radiation
 * data on a TFT with LVGL, connects to WiFi with OTA updates, and charts data using fixed intervals.
 * 
 * The PCNT polling is now performed every 100ms with an accumulator so that high‐frequency pulses are less likely to be missed.
 */

// Debug configuration
// Uncomment the line below to enable debug output at compile time
#define DEBUG

// Runtime debug flag - can be toggled via serial command
bool debugEnabled = true;  // Set to true by default to see debug output immediately

#ifdef DEBUG
    #define DEBUG_TIMESTAMP() do { \
        if (debugEnabled) { \
            unsigned long ms = millis(); \
            unsigned int seconds = ms / 1000; \
            unsigned int minutes = seconds / 60; \
            unsigned int hours = minutes / 60; \
            unsigned int days = hours / 24; \
            seconds %= 60; \
            minutes %= 60; \
            hours %= 24; \
            char timestamp[20]; \
            snprintf(timestamp, sizeof(timestamp), "[%d:%02d:%02d.%03d] ", \
                    (int)days * 24 + (int)hours, (int)minutes, (int)seconds, (int)(ms % 1000)); \
            Serial.print(timestamp); \
        } \
    } while(0)
    
    #define DEBUG_PRINT(x) do { if (debugEnabled) { DEBUG_TIMESTAMP(); Serial.print(x); } } while(0)
    #define DEBUG_PRINTLN(x) do { if (debugEnabled) { DEBUG_TIMESTAMP(); Serial.println(x); } } while(0)
    #define DEBUG_PRINTF(...) do { if (debugEnabled) { DEBUG_TIMESTAMP(); Serial.printf(__VA_ARGS__); } } while(0)
#else
    #define DEBUG_TIMESTAMP()
    #define DEBUG_PRINT(x)
    #define DEBUG_PRINTLN(x)
    #define DEBUG_PRINTF(...)
#endif

/*******************************************************************************
 * Includes
 ******************************************************************************/ 
#include <lvgl.h>
#include <TFT_eSPI.h>
#include "ui.h"           // Declarations for UI objects and functions
#include <WiFi.h>
#include <time.h>
#include <Preferences.h>
#include "dashboard.h"    // Function getDashboardPage()
#include <WebServer.h>
#include <ElegantOTA.h>
#include <ESPmDNS.h>      // Include mDNS support
#include "driver/pcnt.h"  // ESP32 pulse counter driver
#include <ArduinoJson.h>
#include "radiation_data.h" // Export radiation data to other modules
#include "freertos/FreeRTOS.h"
#include "freertos/task.h"
#include "freertos/semphr.h"

/*******************************************************************************
 * Definitions & Constants
 ******************************************************************************/ 
static const uint16_t SCREEN_WIDTH  = 480;
static const uint16_t SCREEN_HEIGHT = 320;

static const uint8_t GEIGER_PULSE_PIN = 9;   ///< GPIO pin connected to the Geiger counter output
static const uint8_t BUZZER_PIN       = 10;    ///< GPIO pin for LEDC buzzer output

static const float CONVERSION_FACTOR = 154.0f; ///< Factor to convert CPM to µSv/h

// Chart settings:
// Chart1: 20 segments, each representing a 3-minute average (1 hour total)
const int CHART1_SEGMENTS         = 20;
static const int CHART1_INTERVAL_SECONDS = 180; // 3 minutes = 180 s

// Chart3: 24 segments, each representing a 1-hour average (24 hours total)
const int CHART3_SEGMENTS         = 24;
static const int CHART3_INTERVAL_SECONDS = 3600; // 1 hour = 3600 s

// Alarm tone parameters (in Hz and ms)
#define ALARM_FREQ1 1000
#define ALARM_FREQ2 1500
#define ALARM_TONE_DURATION 200   ///< Tone duration in ms
#define ALARM_PAUSE_DURATION 50   ///< Pause between tones in ms

// PCNT parameters – note the PCNT hardware counter is 16-bit
static const pcnt_unit_t PCNT_UNIT = PCNT_UNIT_0;
static const int PULSE_HISTORY_SIZE = 60;   ///< 60 one-second intervals in a ring buffer

// LVGL display buffer and UI chart series
static lv_disp_draw_buf_t draw_buf;
static lv_color_t buf[ SCREEN_WIDTH * SCREEN_HEIGHT / 10 ];

// Ring buffers for chart data
float chart1Buffer[CHART1_SEGMENTS] = {0.0f}; ///< 3‑minute averages for Chart1
float chart3Buffer[CHART3_SEGMENTS] = {0.0f}; ///< 1‑hour averages for Chart3
static int chart1Index = 0;  ///< Write index for Chart1
static int chart3Index = 0;  ///< Write index for Chart3

// Maximum values for dynamic chart scaling
static float chart1MaxValue = 1.0f; ///< Maximum value for Chart1, initialized to 1.0 minimum
static float chart3MaxValue = 1.0f; ///< Maximum value for Chart3, initialized to 1.0 minimum

// Scale factor for chart values (LVGL charts only support integers)
static const int CHART_SCALE_FACTOR = 100; ///< Multiply µSv/h by 100 to preserve 2 decimal places

// Accumulators for chart intervals
static float chart1AccumulatedCpm = 0.0f;
static float chart3AccumulatedCpm = 0.0f;
static float chart1ElapsedSec     = 0.0f;
static float chart3ElapsedSec     = 0.0f;

static lv_chart_series_t* chart1Series = nullptr;
static lv_chart_series_t* chart3Series = nullptr;

// UI objects declared in ui.h
extern lv_obj_t* ui_CurrentRad;
extern lv_obj_t* ui_AverageRad;
extern lv_obj_t* ui_MaximumRad;
extern lv_obj_t* ui_CumulativeRad;
extern lv_obj_t* ui_Chart1;
extern lv_obj_t* ui_Chart3;
extern lv_obj_t* ui_CurrentAlarm;    ///< Current radiation alarm threshold label
extern lv_obj_t* ui_CumulativeAlarm; ///< Cumulative dose alarm threshold label

extern lv_obj_t* ui_Startup_screen;       ///< Startup screen (shown while connecting)
extern lv_obj_t* ui_InitialScreen; ///< Screen shown after connection attempt
extern lv_obj_t* ui_OnStartup;     ///< Checkbox for auto–connect on startup
extern lv_obj_t* ui_CurrentSpinbox;    ///< Spinbox for current alarm value
extern lv_obj_t* ui_CumulativeSpinbox;  ///< Spinbox for cumulative alarm value
extern lv_obj_t* ui_EnableAlarmsCheckbox; ///< Checkbox to enable/disable alarms
extern lv_obj_t* ui_SSID;
extern lv_obj_t* ui_PASSWORD;
extern lv_obj_t* ui_WIFIINFO;
extern lv_obj_t* ui_Connect;

// Radiation measurement variables
float currentuSvHr      = 0.0f; ///< Instantaneous dose rate (µSv/h)
float averageuSvHr      = 0.0f; ///< Average dose rate (µSv/h)
float maxuSvHr          = 0.0f; ///< Maximum dose rate (µSv/h)
float cumulativemSv     = 0.0f; ///< Cumulative dose (mSv)

unsigned long totalCounts = 0;   ///< Total pulse count (software accumulation)
unsigned long startTime   = 0;     ///< Measurement start time (ms)
unsigned long lastLoop    = 0;     ///< Last loop time (ms)

// For pulse history: we store the number of pulses counted in each 1-second interval
static int pulseHistory[PULSE_HISTORY_SIZE] = {0};
static int pulseHistoryIndex                = 0;
// PCNT hardware returns a 16-bit value
static int16_t lastPCNTCount16 = 0; 
// We now poll the PCNT counter every 100ms
static unsigned long lastPulsePollTime = 0;
// And we accumulate differences over a 1-second period
static int pulseDiffAccumulator = 0;
static unsigned long pulseAccumulationTime = 0;

// LEDC buzzer alarm variables
bool alarmToneToggle = false;
unsigned long lastAlarmMillis = 0;

// New global flag to disable the alarm (set to disabled by default)
bool alarmDisabled = true;

// Preferences for WiFi settings
Preferences preferences;
static String wifi_ip = "";

// OTA support
WebServer server(80);
bool otaInitialized = false;
// Flag to track if user has acknowledged the OTA warning
bool otaWarningAcknowledged = false;

// Add this to the global variables section
static const int SMOOTHING_WINDOW_SIZE = 5;  // Size of moving average window
static float currentReadingsWindow[SMOOTHING_WINDOW_SIZE] = {0};
static int currentReadingIndex = 0;

// Battery monitoring variables
// Disable battery monitoring since the device is USB powered
// const int BATTERY_VOLTAGE_PIN = 34;        // ADC pin connected to the battery voltage divider
// const float BATTERY_LOW_THRESHOLD = 3.3;   // Voltage threshold for low battery warning
// const float BATTERY_CRITICAL_THRESHOLD = 3.0; // Voltage threshold for critical battery warning
// const unsigned long BATTERY_CHECK_INTERVAL = 60000; // Check battery every minute (in milliseconds)
// unsigned long lastBatteryCheckTime = 0;
// bool batteryLowWarningDisplayed = false;
// bool batteryCriticalWarningDisplayed = false;

// Add to global declarations
static const unsigned long DISPLAY_TIMEOUT = 300000;  // 5 minutes in milliseconds
static unsigned long lastUserInteractionTime = 0;
static bool isDisplayDimmed = false;
static uint8_t normalBrightness = 128;  // Adjust this value as needed
static uint8_t dimmedBrightness = 20;   // Adjust this value as needed

// Core-specific task handles
TaskHandle_t pulseTaskHandle = NULL;
TaskHandle_t uiTaskHandle = NULL;

// Mutex for thread-safe data access
SemaphoreHandle_t dataMutex = NULL;

// Ring buffer for real-time pulse data
#define PULSE_BUFFER_SIZE 20  // 20 samples at 50ms = 1 second of data
struct PulseData {
    int16_t count;
    unsigned long timestamp;
};
PulseData pulseBuffer[PULSE_BUFFER_SIZE];
int pulseBufferIndex = 0;

// Function prototypes for core-specific tasks
void pulseTask(void *parameter);
void uiTask(void *parameter);

/*******************************************************************************
 * Function Prototypes
 ******************************************************************************/ 
void initSerial();
void initTFT();
void initLVGL();
void assignChartSeries();
void clearCharts();
void initPulseCounter();
void initBuzzer();
void playAlarmTone(uint32_t freq);
void stopAlarmTone();
void updatePulseHistory();
int getRealTimeCPM();
void updateRealTimeStats(float cpm, float dtSec);
void updateLabels();
void accumulateCharts(float cpm, float dtSec);
void drawChart1();
void drawChart3();
void updateChartYAxis(lv_obj_t* chart, lv_chart_series_t* series, float maxValue);
static void chart_draw_event_cb(lv_event_t * e);
bool connectToWiFi(const char* ssid, const char* password);
static void connect_btn_event_cb(lv_event_t *e);
void tryAutoConnect();
static void wifi_connect_timer_cb(lv_timer_t * timer);
static void onstartup_checkbox_event_cb(lv_event_t * e);
static void alarms_checkbox_event_cb(lv_event_t * e);
static void spinbox_changed_event_cb(lv_event_t * e);
void saveAlarmSettings();
void loadAlarmSettings();
void checkAlarms();
// void checkBatteryLevel(); // Battery monitoring disabled - USB powered
// Make this static to avoid multiple definition conflicts with dashboard.cpp
static String getRadiationDataJson();
// Export function that can be called from other files
String getRadiationDataJsonExport();
void managePower();
void restoreDisplayBrightness();
static void touch_event_cb(lv_event_t * e);
void setupPowerManagement();
// Function to serve the OTA warning page
void serveOtaWarningPage();

// Function to process serial commands
void processSerialCommands() {
    if (Serial.available()) {
        String command = Serial.readStringUntil('\n');
        command.trim();
        
        if (command == "debug on") {
            debugEnabled = true;
            Serial.println("Debug output enabled");
        } 
        else if (command == "debug off") {
            debugEnabled = false;
            Serial.println("Debug output disabled");
        }
        else if (command == "status") {
            Serial.println("=== Radiation Detector Status ===");
            Serial.printf("Debug: %s\n", debugEnabled ? "ON" : "OFF");
            Serial.printf("Current radiation: %.3f µSv/h\n", currentuSvHr);
            Serial.printf("Average radiation: %.3f µSv/h\n", averageuSvHr);
            Serial.printf("Maximum radiation: %.3f µSv/h\n", maxuSvHr);
            Serial.printf("Cumulative dose: %.3f mSv\n", cumulativemSv);
            Serial.printf("Total counts: %lu\n", totalCounts);
            Serial.printf("CPM: %d\n", getRealTimeCPM());
            Serial.printf("Alarms: %s\n", alarmDisabled ? "DISABLED" : "ENABLED");
            Serial.printf("WiFi: %s\n", WiFi.status() == WL_CONNECTED ? "CONNECTED" : "DISCONNECTED");
            if (WiFi.status() == WL_CONNECTED) {
                Serial.printf("IP: %s\n", wifi_ip.c_str());
            }
        }
    }
}

/*******************************************************************************
 * Buzzer & LEDC Alarm Functions
 ******************************************************************************/ 
void initBuzzer() {
    ledcSetup(0, 2000, 8);  // Default frequency 2000 Hz
    ledcAttachPin(BUZZER_PIN, 0);
    ledcWrite(0, 0);
}

void playAlarmTone(uint32_t freq) {
    ledcSetup(0, freq, 8);
    ledcWrite(0, 128);
}

void stopAlarmTone() {
    ledcWrite(0, 0);
}

/*******************************************************************************
 * Alarm Checkbox Event Callback
 ******************************************************************************/ 
static void alarms_checkbox_event_cb(lv_event_t * e) {
    lv_obj_t * checkbox = lv_event_get_target(e);
    bool isChecked = lv_obj_has_state(checkbox, LV_STATE_CHECKED);
    
    // Update the global state
    alarmDisabled = !isChecked;
    
    DEBUG_PRINTF("Checkbox state changed: %s (alarm %s)\n", 
                isChecked ? "CHECKED" : "UNCHECKED",
                alarmDisabled ? "DISABLED" : "ENABLED");
    
    // Save all alarm settings including the enabled state
    saveAlarmSettings();
    
    // If alarms are disabled, make sure to stop any active tones
    if (alarmDisabled) {
        stopAlarmTone();
    }
}

/**
 * @brief Callback for when spinbox values change
 * 
 * This handler saves the alarm settings whenever a spinbox value changes.
 */
static void spinbox_changed_event_cb(lv_event_t * e) {
    lv_obj_t * spinbox = lv_event_get_target(e);
    char buffer[16];
    
    // Update corresponding alarm label when spinbox value changes
    if (spinbox == ui_CurrentSpinbox && ui_CurrentAlarm) {
        int32_t currentValue = lv_spinbox_get_value(ui_CurrentSpinbox);
        snprintf(buffer, sizeof(buffer), "%.1f", (float)currentValue / 10.0f);
        lv_label_set_text(ui_CurrentAlarm, buffer);
    } 
    else if (spinbox == ui_CumulativeSpinbox && ui_CumulativeAlarm) {
        int32_t cumulativeValue = lv_spinbox_get_value(ui_CumulativeSpinbox);
        snprintf(buffer, sizeof(buffer), "%.1f", (float)cumulativeValue / 10.0f);
        lv_label_set_text(ui_CumulativeAlarm, buffer);
    }
    
    // Save the updated spinbox values and current alarm state
    saveAlarmSettings();
    DEBUG_PRINTLN("Spinbox value changed, alarm settings saved");
}

/*******************************************************************************
 * Alarm Settings Management
 ******************************************************************************/ 
void saveAlarmSettings() {
    // Check if the UI components are initialized
    if (!ui_EnableAlarmsCheckbox || !ui_CurrentSpinbox || !ui_CumulativeSpinbox) {
        DEBUG_PRINTLN("ERROR: Cannot save alarm settings - UI not initialized!");
        return;
    }

    preferences.begin("settings", false);
    
    // Save current alarm threshold from spinbox
    int32_t currentValue = lv_spinbox_get_value(ui_CurrentSpinbox);
    preferences.putInt("currentAlarm", currentValue);
    
    // Save cumulative alarm threshold from spinbox
    int32_t cumulativeValue = lv_spinbox_get_value(ui_CumulativeSpinbox);
    preferences.putInt("cumulativeAlarm", cumulativeValue);
    
    // Save alarm enabled state
    bool isAlarmEnabled = !alarmDisabled;
    preferences.putBool("alarmEnabled", isAlarmEnabled);
    
    // Always flush to ensure data is written
    preferences.end();
    
    DEBUG_PRINTF("Alarm settings saved: Current=%.1f µSv/h, Cumulative=%.1f mSv, Alarms %s\n", 
                 (float)currentValue / 10.0f, 
                 (float)cumulativeValue / 10.0f, 
                 alarmDisabled ? "DISABLED" : "ENABLED");
}
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
void loop() {
    // Main loop is now empty as tasks handle everything
    vTaskDelay(pdMS_TO_TICKS(1000)); // Prevent watchdog trigger
}

/*******************************************************************************
 * Other Functions (Initialization, UI Setup, etc.)
 ******************************************************************************/ 
void initSerial() {
    Serial.begin(115200);
    delay(50);  // Short delay to allow serial to initialize
    Serial.flush();  // Flush any pending data
    DEBUG_PRINTLN("Initializing Serial...");
}

void initTFT() {
    static TFT_eSPI tft(SCREEN_WIDTH, SCREEN_HEIGHT);
    tft.begin();
    tft.setRotation(1);
    uint16_t calData[5] = {300, 3597, 187, 3579, 6};
    tft.setTouch(calData);
    DEBUG_PRINTLN("TFT initialized.");
}

void initLVGL() {
    lv_init();
    lv_disp_draw_buf_init(&draw_buf, buf, NULL, SCREEN_WIDTH * SCREEN_HEIGHT / 10);
    static lv_disp_drv_t disp_drv;
    lv_disp_drv_init(&disp_drv);
    disp_drv.hor_res = SCREEN_WIDTH;
    disp_drv.ver_res = SCREEN_HEIGHT;
    disp_drv.flush_cb = [](lv_disp_drv_t *drv, const lv_area_t *area, lv_color_t *color_p) {
        static TFT_eSPI tftDisp(SCREEN_WIDTH, SCREEN_HEIGHT);
        static bool initted = false;
        if (!initted) {
            tftDisp.begin();
            tftDisp.setRotation(1);
            initted = true;
        }
        uint32_t w = (area->x2 - area->x1 + 1);
        uint32_t h = (area->y2 - area->y1 + 1);
        tftDisp.startWrite();
        tftDisp.setAddrWindow(area->x1, area->y1, w, h);
        tftDisp.pushColors((uint16_t *)&color_p->full, w * h, true);
        tftDisp.endWrite();
        lv_disp_flush_ready(drv);
    };
    disp_drv.draw_buf = &draw_buf;
    lv_disp_drv_register(&disp_drv);

    static lv_indev_drv_t indev_drv;
    lv_indev_drv_init(&indev_drv);
    indev_drv.type = LV_INDEV_TYPE_POINTER;
    indev_drv.read_cb = [](lv_indev_drv_t *drv, lv_indev_data_t *data) {
        static TFT_eSPI tftTouch(SCREEN_WIDTH, SCREEN_HEIGHT);
        static bool inittedTouch = false;
        if (!inittedTouch) {
            tftTouch.begin();
            tftTouch.setRotation(1);
            uint16_t cData[5] = {267, 3646, 198, 3669, 6};
            tftTouch.setTouch(cData);
            inittedTouch = true;
        }
        uint16_t x, y;
        bool touched = tftTouch.getTouch(&y, &x, 600);
        if (!touched)
            data->state = LV_INDEV_STATE_REL;
        else {
            data->state = LV_INDEV_STATE_PR;
            data->point.x = x;
            data->point.y = y;
        }
    };
    lv_indev_drv_register(&indev_drv);

    ui_init();
    DEBUG_PRINTLN("LVGL initialized + UI created.");
}

void updateRealTimeStats(float cpm, float dtSec) {
    // Calculate raw value using the proper conversion factor
    // CONVERSION_FACTOR is 153.8, so we divide CPM by this value to get µSv/h
    float rawCurrentuSvHr = cpm / CONVERSION_FACTOR;
    
    // Add to the smoothing window
    currentReadingsWindow[currentReadingIndex] = rawCurrentuSvHr;
    currentReadingIndex = (currentReadingIndex + 1) % SMOOTHING_WINDOW_SIZE;
    
    // Calculate smoothed value (moving average)
    float sum = 0.0f;
    int validReadings = 0;
    for (int i = 0; i < SMOOTHING_WINDOW_SIZE; i++) {
        if (currentReadingsWindow[i] > 0 || i < currentReadingIndex) {
            sum += currentReadingsWindow[i];
            validReadings++;
        }
    }
    // Avoid division by zero
    currentuSvHr = (validReadings > 0) ? (sum / validReadings) : 0.0f;
    
    // Update average using total counts since start
    unsigned long now = millis();
    float totalTimeMin = (float)(now - startTime) / 60000.0f;
    if (totalTimeMin > 0.0f) {
        float avgCPM = (float)totalCounts / totalTimeMin;
        averageuSvHr = avgCPM / CONVERSION_FACTOR;
    }
    
    // Update maximum if current reading is higher (but only if it seems valid)
    if (currentuSvHr > maxuSvHr && currentuSvHr < 100.0f) { // Sanity check upper limit
        maxuSvHr = currentuSvHr;
    }
    
    // Calculate dose increment in µSv, then convert to mSv (1 mSv = 1000 µSv)
    // Formula: (µSv/h) / (3600 sec/h) * dt / 1000
    float doseIncrement_mSv = (currentuSvHr / 3600.0f) * dtSec / 1000.0f;
    cumulativemSv += doseIncrement_mSv;
}

void updateLabels() {
    char buffer[16];
    snprintf(buffer, sizeof(buffer), "%.2f", currentuSvHr);
    lv_label_set_text(ui_CurrentRad, buffer);
    snprintf(buffer, sizeof(buffer), "%.2f", averageuSvHr);
    lv_label_set_text(ui_AverageRad, buffer);
    snprintf(buffer, sizeof(buffer), "%.2f", maxuSvHr);
    lv_label_set_text(ui_MaximumRad, buffer);
    snprintf(buffer, sizeof(buffer), "%.2f", cumulativemSv);
    lv_label_set_text(ui_CumulativeRad, buffer);
    
    // Update alarm threshold labels on the main screen
    if (ui_CurrentSpinbox && ui_CurrentAlarm) {
        int32_t currentValue = lv_spinbox_get_value(ui_CurrentSpinbox);
        float currentThreshold = (float)currentValue / 10.0f;
        snprintf(buffer, sizeof(buffer), "%.1f", currentThreshold);
        lv_label_set_text(ui_CurrentAlarm, buffer);
    }
    
    if (ui_CumulativeSpinbox && ui_CumulativeAlarm) {
        int32_t cumulativeValue = lv_spinbox_get_value(ui_CumulativeSpinbox);
        float cumulativeThreshold = (float)cumulativeValue / 10.0f;
        snprintf(buffer, sizeof(buffer), "%.1f", cumulativeThreshold);
        lv_label_set_text(ui_CumulativeAlarm, buffer);
    }
}
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

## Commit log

2025-01-25 Migrated from Arduino IDE to PlatformIO
2025-03-23 Web UI Bug Fixes
    [Radiation-Detector.cpp]
2025-04-13 Improved Voltage screen to start developments
2025-04-15 Initial Commit of PCB Files
2025-04-15 Initial PCB Files Commit
    [Esp32s3 pinout sheet.xlsx, PTS645SH50SMTR92LFS.PcbLib, PTS645SH50SMTR92LFS.SchLib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]
2025-04-25 updated pcb
    [1N5819HW-7-F.PcbLib, 1N5819HW-7-F.SchLib, 217179-0001.PcbLib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]
2025-05-06 Improved Schematic Design
    [GeigerCircuit.SchDoc, Geiger_Circuit.SchDoc, IO_Ports.SchDoc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]
2025-05-07 touchscreen library created
    [Schlib.SchLib]
2025-06-03 Fix radiation unit conversion
    [Radiation-Detector.cpp]
2025-07-14 Changed geiger setup to anode - coupling
    [Geiger_Circuit.SchDoc, Schlib.SchLib]
2025-07-22 Added periferals page back, (was accidentally deleted)
    [Peripherals.SchDoc, RadiationDetector.PrjPcb, Schlib.SchLib]
2025-07-26 Add Battery schematic and update project structure
    Added battery management/ charging circuitry, redesigned power structure, removing linear regulators and adding a buck converter
    [Battery.SchDoc, Geiger_Circuit.SchDoc, IO_Ports.SchDoc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]
2025-07-26 Improved Schematics
    [Geiger_Circuit.SchDoc, Peripherals.SchDoc, Power.SchDoc]
2025-07-27 Finished First Schematic Revision
    [Geiger_Circuit.SchDoc, IO_Ports.SchDoc, Microcontroller_Unit.SchDoc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]
2025-07-27 Added Power Off Switch
    [Power.SchDoc, RadiationDetector.PrjPcb, Schlib.SchLib]
2025-07-27 updated diferential pairs
    [IO_Ports.SchDoc]
2025-07-27 Create Power SCH ECO 27-07-2025 20-47-46.LOG
2025-07-27 Added Component Footprints
    [217179-0001.PcbLib, 217179-0001.SchLib, CP2102N-A02-GQFN28.PcbLib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]
2025-07-28 Updated Button 3D Model
    [PTS645SL43SMTR92-LFS.STEP, PcbLib.PcbLib]
2025-08-03 Finished adding off-the-shelf footprints
    [Microcontroller_Unit.SchDoc, PMEG4010BEA,115.stp, PcbLib.PcbLib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]
2025-08-05 added custom footprints
    [IO_Ports.SchDoc, MBRS240LT3G.stp, PcbLib.PcbLib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]
2025-08-06 Created LCD Footprint
    [PcbLib.PcbLib, ST7796SDisplay.step, Schlib.SchLib]
2025-08-10 Finished updating component footprints, created board
    [Geiger_Circuit.SchDoc, IO_Ports.SchDoc, Microcontroller_Unit.SchDoc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]
2025-08-10 placed components on pcb layout
    [PcbLib.PcbLib, Peripherals.SchDoc, RadiationDetector.PcbDoc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]
2025-08-11 Added hv circuitry to layout
    [Geiger_Circuit.SchDoc, PcbLib.PcbLib, User Library-DO-214AC SMA.STEP]
2025-08-11 Placed all the components in the board
    [Microcontroller_Unit.SchDoc]
2025-08-11 Small layout fix
    [PcbLib.PcbLib]
2025-08-13 Added testpoints
    [Geiger_Circuit.SchDoc, IO_Ports.SchDoc, PcbLib.PcbLib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]
2025-08-13 Redefined ESP32S3 Pinout
    [Geiger_Circuit.SchDoc, Microcontroller_Unit.SchDoc, Peripherals.SchDoc]
2025-08-14 Updated layout
    [IO_Ports.SchDoc, PcbLib.PcbLib]
2025-08-16 Finished preliminary layout
    [Geiger_Circuit.SchDoc, RadiationDetector.PrjPcb]
2025-08-17 Finished PCB Layout
    [Bill of Materials-RadiationDetector(Prototype).xlsx, Geiger_Circuit.SchDoc, PcbLib.PcbLib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]
2025-08-18 Changed some components as they were out of stock, added decoupling caps
    [Bill of Materials-RadiationDetector(Prototype).xlsx, Geiger_Circuit.SchDoc, Microcontroller_Unit.SchDoc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]
2025-08-18 Update RadiationDetector PCB design and add history
    Updated the RadiationDetector.PcbDoc file with new changes and added a new historical backup RadiationDetector.~(87).PcbDoc.Zip for version tracking.
2025-08-18 Update RadiationDetector PCB and add history backup
    Updated the RadiationDetector.PcbDoc file with new changes and added a backup of the previous version to the History directory as RadiationDetector.~(88).PcbDoc.Zip.
2025-08-22 Fixed keyboard not showing properly on config screen
    [Pick Place for RadiationDetector(Prototype).csv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]
2025-08-27 File cleanup
    [Geiger_Circuit.SchDoc, Scintillator_Circuit.SchDoc]
2025-10-24 Fixed issue where the device got stuck on the startup screen
    [Radiation-Detector.cpp]
